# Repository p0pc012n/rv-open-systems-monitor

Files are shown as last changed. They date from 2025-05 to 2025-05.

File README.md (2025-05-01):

# rv-open-systems-monitor
ePaper Systems Information Display for RVs, Powered by Raspberry Pi

Open Source solution to provide a drop in replacement to system monitor panels in RVs (Motorhomes, Travel Trailers, Campers)
This started as a personal project after i got tired checking the LEDS and trying to remember what the last status was. The ePaper display will retain the system status image even when powered off.
The intended folder structure is set up in anticipation if this project is picked up and other RV system monitor configurations are added. The goal is to aim for modularity.

This system ePaper display is powered by a Raspberry Pi Pico 2 W. There is potential for wireless notfications, but I have not gotten around to it.
The display is a Waveshare 2.9in Four Color Grayscale ePaper display for Pico, and must be used in order for this code to work.
The STL files are a retrofitted display bezel to allow the assembly to clip into the existing system monitor frame and use the existing wiring harness.

Getting Started:
1. Flash Raspberry Pi Pico 2 (2 or 2W) with latest firmware from official source. (Older Pico may work, but it's untested)
2. Download the folder "Pico" in the intended display size for the system monitor.
3. Download Thonny or a similar micropython IDE that can communicate with the Raspberry Pi Pico 2 (RP).
3. After Flashing Firmware to the RP, open Thonny and connect to the RP.
4. Using Thonny, Upload the "main.py" from the "Pico" folder on your PC to the RP.
5. Using Thonny, Upload the folder "lib" from the "Pico" folder on your PC to the RP.
6. The file structure in the root folder of your RP should now only contain the "main.py" and the folder "lib".
7. If you have trouble, uploading the "lib" folder, you can always move all files one at a time, however this will be very time consuming.
8. Download the Wavehsare driver for the ePaper display and rename it to remove hyphens (-) and extra periods (.) because micropython will have problems (the main.py for the 2.9 display expects it to be named "Pico_ePaper_2_9.py").
9. Using the same method above, upload driver to the "lib" folder on the RP.
Note: For the 2.9in four color grayscale display, use the driver from this fork: [python/Pico_ePaper-2.9.py](https://github.com/p0pc012n/pico_epaper_image/blob/main/python/Pico_ePaper-2.9.py)

Assembly Notes:
1. The Waveshare 2.9 ePaper display has a ribbon cable from the display to the blue display pcb. Ensure that when installing the RP onto the display board headers that the RP microUSB port and the epaper display ribbon cable are on the same side.
2. The 3D Printed Bezel has a cutout for the ePaper display ribbon cable. Ensure the display is oriented on the 3D Printed bezel so that the ribbon cable is in the cutout.

Testing is underway, however I am only able to test this on my travel trailer configuration. 3D Models will vary from system monitor panels. Voltage values may vary wildly between RVs, system monitors, installed batteries, power control boards, etc.

In Testing:
KIB System Monitor found in 2006 Trailmanor model years. Voltage values may be tuned for 12V LifePo4 battery and PD Wildkat board.

Currently Supported:

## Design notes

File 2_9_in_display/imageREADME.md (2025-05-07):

The images used for the display were made in GIMP using a four color grayscale scheme that resulted in RGB values of black (0,0,0), dark gray (23, 23, 23), light gray (103, 103, 103), and white (255, 255, 255) explicitly. The png files were exported at full resolution no scaling in 8bit RGB. I did not use the GIMP export setting for grayscale.

I found the waveshare display driver for the pico version of the 2.9 in grayscale display to be problematic. The original waveshare display unpacks a bytearray and splits it into two images to send to the display and are overlaid.
I forked the original waveshare driver to insert a simple function in the driver, ane then wrote a python script to process my png files on a pc and then send the final bytearrays to the raspberry pi pico.
My forked waveshare driver can be found here: https://github.com/p0pc012n/pico_epaper_image/blob/main/python/Pico_ePaper-2.9.py
My python script for converting .png to bytearrays with more detailed instruction can be found here: https://github.com/p0pc012n/PNG_to_epaper_converter

The main.py combines bytearrays depending on the system status to generate the final image in real time. I implemented further post-processing of the bytearrays except for the base GUI image. I used clean_byte.py to crop all the images representing different system statuses. This allow the main.py to overwrite the bytes at each of the status positions on the display for gray water tank, fresh water tank, and battery respectively.

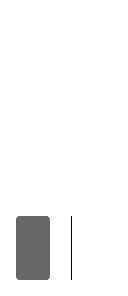
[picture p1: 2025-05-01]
2_9_in_display/images/battery_2_3.png

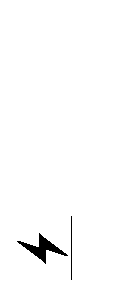
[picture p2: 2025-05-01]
2_9_in_display/images/battery_charge.png

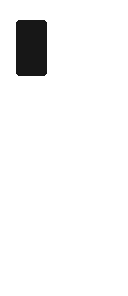
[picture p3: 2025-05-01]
2_9_in_display/images/gray_2_3.png

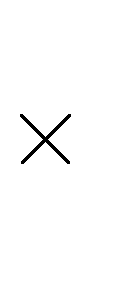
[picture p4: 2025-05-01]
2_9_in_display/images/fresh_empty.png

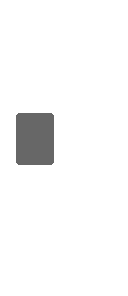
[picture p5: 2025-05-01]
2_9_in_display/images/fresh_2_3.png

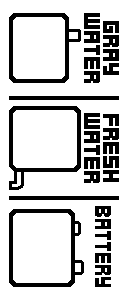
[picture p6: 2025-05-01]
2_9_in_display/images/panel_base.png

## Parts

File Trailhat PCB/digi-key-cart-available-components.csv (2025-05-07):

Index | DigiKey Part # | Manufacturer Part Number | Manufacturer | Description | Customer Reference | Quantity | Backorder | Unit Price | Extended Price
1 | 1655-1N5817CT-ND | 1N5817 | SMC Diode Solutions | DIODE SCHOTTKY 20V 1A DO41 |  | 3 | 0 | $0.18 | $0.72
2 | 1528-5584-ND | 5584 | Adafruit Industries LLC | SHORT PLUG HEADERS FOR RASPBERRY |  | 1 | 0 | $0.95 | $0.95
3 | 493-13396-ND | UKL1C101KPDANA | Nichicon | CAP ALUM 100UF 10% 16V RADIAL TH |  | 1 | 0 | $0.54 | $0.54
4 | 2648-SC1633-ND | SC1633 | Raspberry Pi | RASPBERRY PI PICO 2 W RP2350 |  | 1 | 0 | $7.00 | $7.00
5 | 399-C330C104J2H5TA-ND | C330C104J2H5TA | KEMET | CAP CER 0.1UF 200V X8R RADIAL |  | 1 | 0 | $1.03 | $1.03
6 | 13-MFR-25FBF52-34K8-ND | MFR-25FBF52-34K8 | YAGEO | RES 34.8K OHM 1% 1/4W AXIAL |  | 1 | 0 | $0.04 | $0.39
7 | 10.2KXBK-ND | MFR-25FBF52-10K2 | YAGEO | RES 10.2K OHM 1% 1/4W AXIAL |  | 1 | 0 | $0.04 | $0.39
8 | 13-MFR-25FBF52-5K76-ND | MFR-25FBF52-5K76 | YAGEO | RES 5.76K OHM 1% 1/4W AXIAL |  | 2 | 0 | $0.04 | $0.39
9 | 13-MFR-25FTE52-8K2CT-ND | MFR-25FTE52-8K2 | YAGEO | RES 8.2K OHM 1% 1/4W AXIAL |  | 2 | 0 | $0.04 | $0.37
10 | LM2940T-8.0/NOPB-ND | LM2940T-8.0/NOPB | Texas Instruments | IC REG LINEAR 8V 1A TO220-3 |  | 1 | 0 | $1.77 | $1.77
11 | 2057-PH1RB-07-UA-ND | PH1RB-07-UA | Adam Tech | CONN HEADER R/A 7POS 2.54MM |  | 1 | 0 | $0.18 | $0.18
12 | 1N4728A-ND | 1N4728A | onsemi | DIODE ZENER 3.3V 1W DO41 |  | 3 | 0 | $0.16 | $0.64

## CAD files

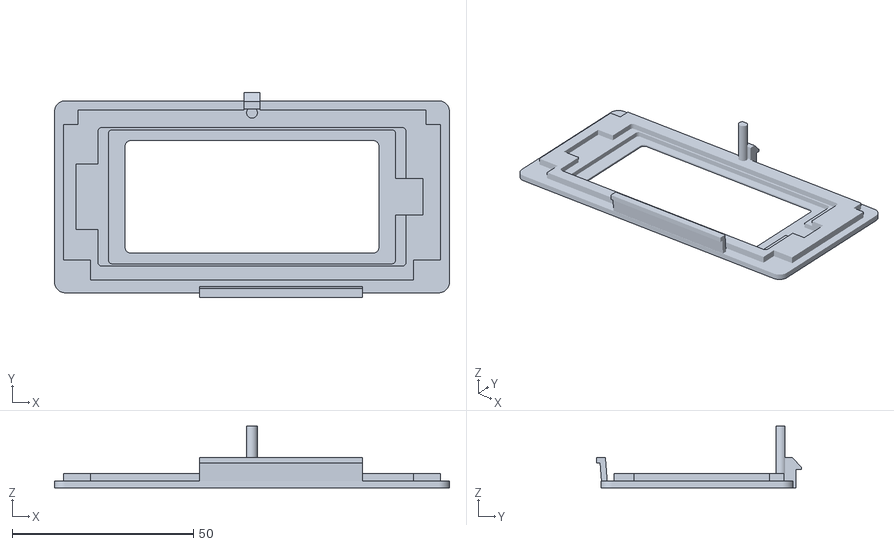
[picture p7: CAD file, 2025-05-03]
3D Models/Trailmanor 2006/display_bezel_V3.stl
109.0 x 56.6 x 17.0

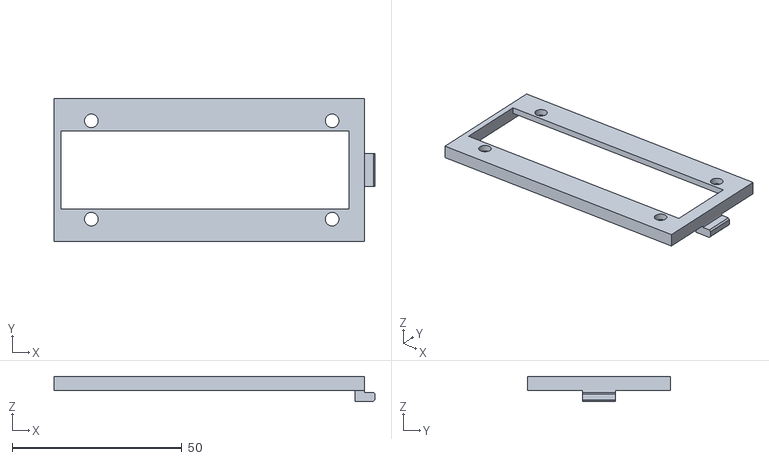
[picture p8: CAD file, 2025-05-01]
3D Models/Trailmanor 2006/display_bezel_bracket_V2.stl
94.6 x 42.2 x 7.47

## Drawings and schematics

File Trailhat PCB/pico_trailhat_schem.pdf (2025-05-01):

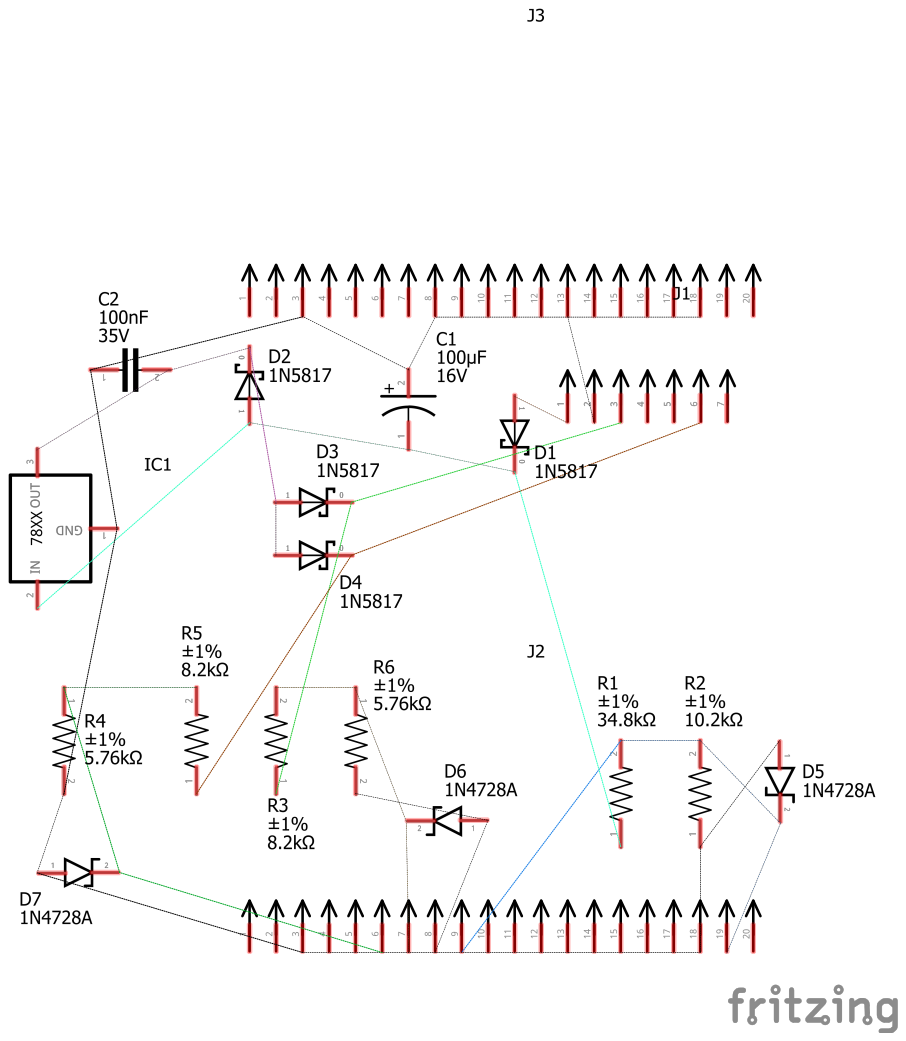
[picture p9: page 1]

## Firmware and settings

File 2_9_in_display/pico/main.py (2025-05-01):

# MicroPython main script
from machine import Pin, ADC
import utime
from Pico_ePaper_2_9 import EPD_2in9_Portrait
from trailhat import TrailScreen
from panel_base_x24 import x24_image_data as panel_x24
from panel_base_x26 import x26_image_data as panel_x26

# Configure power switch (True = rocker/toggle switch, Fasle = momentary rocker switch)
constant_power = False

# Configure pins to system sensors
gray_water_pin = ADC(Pin(26))
fresh_water_pin = ADC(Pin(27))
battery_pin = ADC(Pin(29))

# PD 4655L Wildkat battery levels
# Boost Mode 14.4 Volts
# Normal Mode 13.6 Volts
# Storage Mode 13.2 Volts
# Desulfation Mode 14.4 Volts every 21 hours for a period of 15 minutes to prevent battery stratification

# Pico Battery Status:
# Charge: >= 3.08 V
# Full: 2.98 <= V < 3.08
# 2/3:  2.805 V < 2.98
# 1/3:2.63 <= V < 2.805
# empty: V < 2.63

# KIB M-Panel readout
# Battery Charge 12.7 to 12.85
# Battery Good 12.10 to 12.15
# Battery Fair 11.60 to 11.65
# Battery Low 6.0 to --

# KIB M-Panel tanks readout
# Orange Full: 0 Ohms
# Green 2/3: 68k Ohms
# Yellow 1/3: 188k Ohms
# Red Signal
# White Ground

# Fresh Tank Status:
# Ground: > 2.72 V empty
# Yellow:  1.81 < V <= 2.72 1/3
# Green: 0.91 < V <= 1.81 2/3
# Orange: V <= 0.91 full

# Gray Tank Status:
# Ground: > 2.72 V empty
# Yellow:  1.81 < V <= 2.72 1/3
# Green: 0.91 < V <= 1.81 2/3
# Orange: V <= 0.91 full


def read_voltage(pico_pin):
    raw = pico_pin.read_u16()
    voltage = raw * 3.3 / 65535
    return voltage


def tank_level(voltage):
    if voltage > 2.72:
        return "0"
    elif 1.81 < voltage <= 2.72:
        return "1"
    elif 0.91 < voltage <= 1.81:
        return "2"
    elif voltage <= 0.91:
        return "3"


def battery_level(voltage):
    if voltage < 2.63:
        return "0"
    elif 2.63 <= voltage < 2.81:
        return "1"
    elif 2.81 <= voltage < 2.98:
        return "2"
    elif 2.98 <= voltage < 3.08:
        return "3"
    elif voltage >= 3.08:
        return "4"


def format_tank(pico_voltage):
    scaled_volt = pico_voltage * (8200 + 5760) / 5760
    rounded_volt = round(scaled_volt, 2)
    # format_volt = "{:.2f}".format(rounded_volt)
    return rounded_volt


def format_battery(pico_voltage):
    scaled_volt = pico_voltage * (34800 + 10200) / 10200
    rounded_volt = round(scaled_volt, 2)
    # format_volt = "{:.2f}".format(rounded_volt)
    return rounded_volt


def get_status(panel_x24, panel_x26, gray_water_pin, fresh_water_pin, battery_pin):
    # initialize class
    start_screen = TrailScreen(panel_x24, panel_x26)

    # read pins
    read_gray = read_voltage(gray_water_pin)
    read_fresh = read_voltage(fresh_water_pin)
    read_battery = read_voltage(battery_pin)

    # debug
    # read_gray = 0.5
    # read_fresh =0.5
    # read_battery =3.09

    # scale voltage
    gray_volt = format_tank(read_gray)
    fresh_volt = format_tank(read_fresh)
    battery_volt = format_battery(read_battery)

    # determine status
    gray_status = tank_level(read_gray)
    fresh_status = tank_level(read_fresh)
    battery_status = battery_level(read_battery)

    return (
        gray_volt,
        fresh_volt,
        battery_volt,
        gray_status,
        fresh_status,
        battery_status,
    )


def update_display(
    gray_status, fresh_status, battery_status, gray_volt, fresh_volt, battery_volt
):
    start_screen.process_gray(gray_status)
    start_screen.process_fresh(fresh_status)
    start_screen.process_battery(battery_status)

    start_screen.process_voltage_readings(gray_volt, fresh_volt, battery_volt)

    get_x24, get_x26 = start_screen.get_screen()

    # call epd driver and write to screen
    epd = EPD_2in9_Portrait()
    epd.Clear(0xFF)
    epd.fill(0xFF)
    epd.init_4Gray()
    epd.display_Gray_Image(get_x24, get_x26)
    epd.sleep()


def clear_display():
    epd = EPD_2in9_Portrait()
    epd.init()
    epd.Clear(0xFF)
    epd.fill(0xFF)
    epd.Clear(0xFF)
    epd.sleep()


if constant_power:
    clear_display()
    # Time to clear display for storage and cycle power off
    utime.sleep(1000)
    g_volt, f_volt, b_volt, g_status, f_status, b_status = get_status(
        panel_x24, panel_x26, gray_water_pin, fresh_water_pin, battery_pin
    )
    previous_g_status = g_status
    previous_f_status = f_status
    previous_b_status = b_status
    update_display(
        gray_status, fresh_status, battery_status, gray_volt, fresh_volt, battery_volt
    )
    # Checks status every 20 minutes
    while constant_power:
        g_volt, f_volt, b_volt, g_status, f_status, b_status = get_status(
            panel_x24, panel_x26, gray_water_pin, fresh_water_pin, battery_pin
        )
        if (
            previous_g_status != g_status
            or previous_f_status != f_status
            or previous_b_status != b_status
        ):
            previous_g_status = g_status
            previous_f_status = f_status
            previous_b_status = b_status
            update_display(
                gray_status,
                fresh_status,
                battery_status,
                gray_volt,
                fresh_volt,
                battery_volt,
            )
        utime.sleep(1200000)

else:
    current_time = utime.ticks_ms()
    while current_time < 1500:
        g_volt, f_volt, b_volt, g_status, f_status, b_status = get_status(
            panel_x24, panel_x26, gray_water_pin, fresh_water_pin, battery_pin
        )
        update_display(
            gray_status,
            fresh_status,
            battery_status,
            gray_volt,
            fresh_volt,
            battery_volt,
        )
    clear_display()

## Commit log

2025-05-01 initial project commit
    [display_bezel_V2.stl, display_bezel_bracket_V2.stl]
2025-05-03 Updated the display bezel with better fit clearance in the monitor frame. Moved bottom clip on the bezel towards the outside removing the original cutaway seen on the oem bezel.
    [display_bezel_V2.stl, display_bezel_V3.stl]
2025-05-07 Add files via upload
    digi key compatible csv for available components at time of upload
    [digi-key-cart-available-components.csv]
